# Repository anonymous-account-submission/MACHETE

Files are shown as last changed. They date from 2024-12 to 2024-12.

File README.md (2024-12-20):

# Motor Assisted Commutator to Harness Electronics in Tethered Experiments (MACHETE)

MACHETE is a motor assisted commutator that allows researchers to capture high-fidelity electro-optical data during tethered freely-moving behavior experiments with mice.



# Custom Arduino Printed Circuit Board Shield:
Our motor assisted commutator is driven and controlled by an Arduino Nano 3.x, integrated within a pair of custom printed circuit boards (PCBs) which allow users to interface with both data aquisition computers and existing commercial optogenetic and electrophysiological devices. 



# Commercially Available and Custom Made Parts 

<table class="table table-bordered table-hover table-condensed">
<thead>
<tr>
<th title="Field #1">Part Number</th>
<th title="Field #2">Distributor</th>
<th title="Field #3">Part Name</th>
<th title="Field #4">Distributor Part Number</th>
<th title="Field #5">Quantity Needed</th>
</tr>
</thead>
<tbody>
<tr>
<td align="right">1</td>
<td>Digikey</td>
<td>Micro USB 2.0 Connector</td>
<td>609-4613-1-ND</td>
<td>1</td>
</tr>
<tr>
<td align="right">2</td>
<td>Digikey</td>
<td>Connector Receptacle</td>
<td>WM3917CT-ND</td>
<td>1</td>
</tr>
<tr>
<td align="right">3</td>
<td>Digikey</td>
<td>Resistor 390 Ohm</td>
<td>311-390CRCT-ND</td>
<td>1</td>
</tr>
<tr>
<td align="right">4</td>
<td>Digikey</td>
<td>Toggle Switch</td>
<td>CKN1783CT-ND</td>
<td>1</td>
</tr>
<tr>
<td align="right">5</td>
<td>Digikey</td>
<td>Arduino Nano 3.x</td>
<td>1050-1001-ND</td>
<td>1</td>
</tr>
<tr>
<td align="right">6</td>
<td>Digikey</td>
<td>Mini USB 2.0 Connector</td>
<td>UE25BE5510H-ND</td>
<td>1</td>
</tr>
<tr>
<td align="right">7</td>
<td>Digikey</td>
<td>Right Angle Connector</td>
<td>WM1743-ND</td>
<td>1</td>
</tr>
<tr>
<td align="right">8</td>
<td>Digikey</td>
<td>Resistor 100k Ohm 0805</td>
<td>311-100KCRCT-ND</td>
<td>6</td>
</tr>
<tr>
<td align="right">9</td>
<td>Digikey</td>
<td>Hall Effect Sensor</td>
<td>AS5600-ASOMCT-ND</td>
<td>1</td>
</tr>
<tr>
<td align="right">10</td>
<td>Digikey</td>
<td>Capacitor 1 µF 0805</td>
<td>1276-1066-1-ND</td>
<td>1</td>
</tr>
<tr>
<td align="right">11</td>
<td>Digikey</td>
<td>Capacitor 10 µF 0805</td>
<td>445-7644-1-ND</td>
<td>1</td>
</tr>
<tr>
<td align="right">12</td>
<td>Digikey</td>
<td>Connector Receptacle</td>
<td>WM4783CT-ND</td>
<td>1</td>
</tr>
<tr>
<td align="right">13</td>
<td>Digikey</td>
<td>Resistor 10k Ohm 0805</td>
<td>RMCF0805FT10K0CT-ND</td>
<td>2</td>
</tr>
<tr>
<td align="right">14</td>
<td>Digikey</td>
<td>Motor Driver 20-QFN (3x3)</td>
<td>175-TMC6300-LA-TCT-ND</td>
<td>1</td>
</tr>
<tr>
<td align="right">15</td>
<td>Digikey</td>
<td>Resistor 120 mOhms 0805</td>
<td>RL12S.12FCT-ND</td>
<td>1</td>
</tr>
<tr>
<td align="right">16</td>
<td>Digikey</td>
<td>Capacitor 0.1 µF 0805</td>
<td>478-KGM21NR71H104KTCT-ND</td>
<td>3</td>
</tr>
<tr>
<td align="right">17</td>
<td>Digikey</td>
<td>Brushless DC Motor</td>
<td>1568-ROB-20441-ND</td>
<td>1</td>
</tr>
<tr>
<td align="right">18</td>
<td>Mouser</td>
<td>Red LED</td>
<td>696-SMLFT0805SRCTR</td>
<td>1</td>
</tr>
<tr>
<td align="right">19</td>
<td>Adafruit</td>
<td>M3 x 4mm threaded insert</td>
<td>4255</td>
<td>1 (Pack of 50)</td>
</tr>
<tr>
<td align="right">20</td>
<td>McMaster-Carr</td>
<td>M2 x 4mm threaded insert</td>
<td>94180A312</td>
<td>1 (Pack of 100)</td>
</tr>
<tr>
<td align="right">21</td>
<td>McMaster-Carr</td>
<td>Ball Bearing 6 mm shaft</td>
<td>4668K122</td>
<td>1</td>
</tr>
<tr>
<td align="right">22</td>
<td>McMaster-Carr</td>
<td>M3-0.5 x 6mm screw</td>
<td>91290A111</td>
<td>1</td>
</tr>
<tr>
<td align="right">23</td>
<td>McMaster-Carr</td>
<td>M3-0.5 x 10mm screw</td>
<td>91290A115</td>
<td>1</td>
</tr>
<tr>
<td align="right">24</td>
<td>McMaster-Carr</td>
<td>M2-0.4 x 8mm screw</td>
<td>91290A015</td>
<td>1</td>
</tr>
<tr>
<td align="right">25</td>
<td>Taidacent</td>
<td>Rotary Electrical Slip Ring</td>
<td>734831002031</td>
<td>1</td>
</tr>
<tr>
<td align="right">26</td>
<td>K&J Magnetics, Inc</td>
<td>Magnet (5 mm x 1mm)</td>
<td>D301</td>
<td>1</td>
</tr>
<tr>
<td align="right">27</td>
<td>Maxx Model</td>
<td>M1.6 x 4mm screw</td>
<td>M1640HCS</td>
<td>2</td>
</tr>
<tr>
<td align="right">28</td>
<td>Custom Parts</td>
<td>Top Case</td>
<td>3-D Printing</td>
<td>1</td>
</tr>
<tr>
<td align="right">29</td>
<td>Custom Parts</td>
<td>PCB attachment</td>
<td>3-D Printing</td>
<td>1</td>
</tr>
<tr>
<td align="right">30</td>
<td>Custom Parts</td>
<td>Static PCB</td>
<td>PCB Manufacturing (JLC PCB)</td>
<td>1</td>
</tr>
<tr>
<td align="right">31</td>
<td>Custom Parts</td>
<td>Dynamic PCB</td>
<td>PCB Manufacturing (JLC PCB)</td>
<td>1</td>
</tr>
<tr>
<td align="right">32</td>
<td>Custom Parts</td>
<td>Small Gear</td>
<td>3-D Printing</td>
<td>1</td>
</tr>
<tr>
<td align="right">33</td>
<td>Custom Parts</td>
<td>Shield</td>
<td>3-D Printing</td>
<td>1</td>
</tr>
<tr>
<td align="right">34</td>
<td>Custom Parts</td>
<td>Cable Holder</td>
<td>3-D Printing</td>
<td>1</td>
</tr>
<tr>
<td align="right">35</td>
<td>Custom Parts</td>
<td>Outer Gear</td>
<td>3-D Printing</td>
<td>1</td>
</tr>
</tbody>
</table>

This [document](https://github.com/anonymous-account-submission/MACHETE/blob/bac1c05d11be4005d82bf26546d7f61cbe5a9f60/3-MACHETE-Custom-Parts-Table.pdf) outlines the design of each of the custom pieces and the file types found within this repository that can be used to replicate the system. The following [spreadsheet](https://github.com/anonymous-account-submission/MACHETE/blob/89ad60d1f6e04f39b38d436aee46013fde03fa46/2-MACHETE-Bill-of-Materials-and-Assembly-Spreadsheet.xlsx) outlines the total cost of the motor assisted commutator.  

**Here is a list of the manufacturers we purchased materials from:** 
- Digikey
- Mouser
- Adafruit 
- McMaster-Carr
- Taidacent
- K&J Magnetics, Inc
- Maxx Model

# Step-by-Step Building Guide



This following [guide](https://github.com/anonymous-account-submission/MACHETE/blob/89ad60d1f6e04f39b38d436aee46013fde03fa46/4-MACHETE-Step-by-Step-Guide.pdf) provides a step-by-step walkthrough for building and testing each component of our motor assisted commutator. This document includes diagrams and explanations for assembling each component. 

# Software Installation Guide and Dependencies

Following this installation guide will ensure that your MACHETE system will be able to run the required Arduino IDE sketches to function. 

**Required Software and Applications**:
- [Arduino IDE](https://www.arduino.cc/en/software)
- [BORIS](https://github.com/olivierfriard/BORIS)
  
# Contact

Further information and requests for resources should be directed to and will be fulfilled by the lead author, [Lead Author Name and Email]. Example commutator data is available upon request to the corresponding author, [Corresponding Author Name and Email].

# Citation 

If you replicate this system in your own labs or use parts of our designs and code, we kindly ask that you please cite this [page](https://github.com/anonymous-account-submission/MACHETE) [1].

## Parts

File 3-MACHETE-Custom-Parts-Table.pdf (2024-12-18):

Custom Part and Filetype: | 3-D Rendering

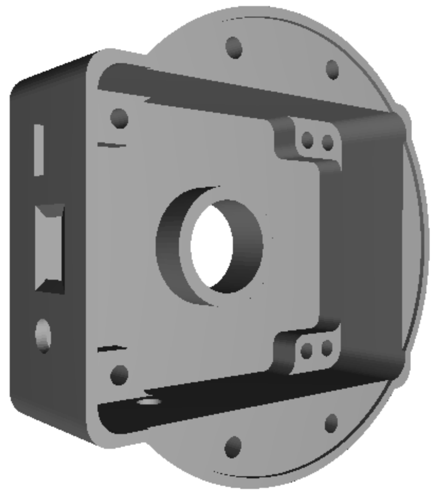
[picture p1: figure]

Top Case Part1_Top_Case.stl

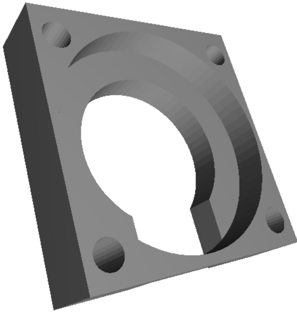
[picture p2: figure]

PCB Attachment Part3_PCB_Attachment.stl

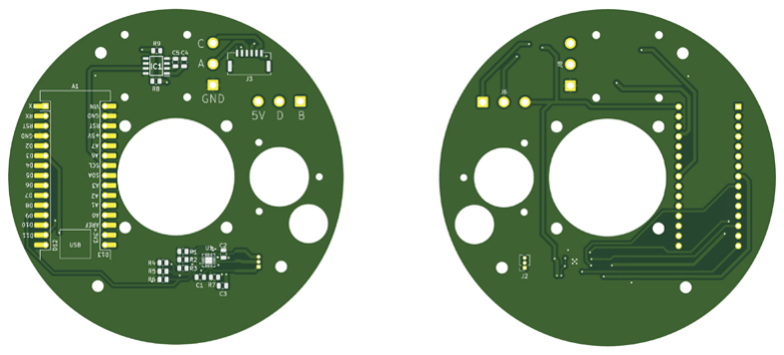
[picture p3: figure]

Static PCB Static_PCB_Fab_Files Folder

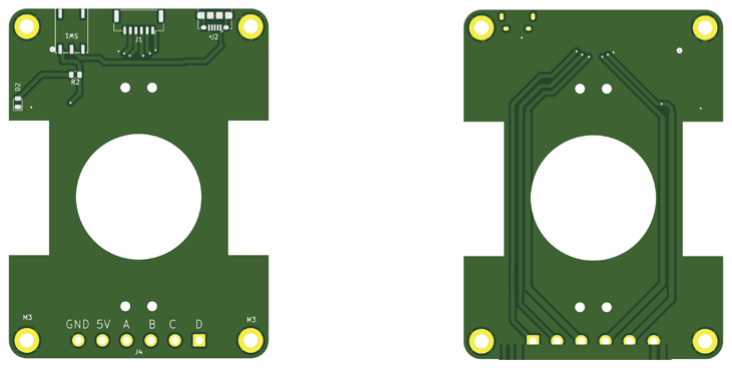
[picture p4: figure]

Dynamic PCB Dynamic_PCB_Fab_Files Folder

Custom Part and Filetype: | 3-D Rendering

Small Gear Part11_Small_Gear.stl

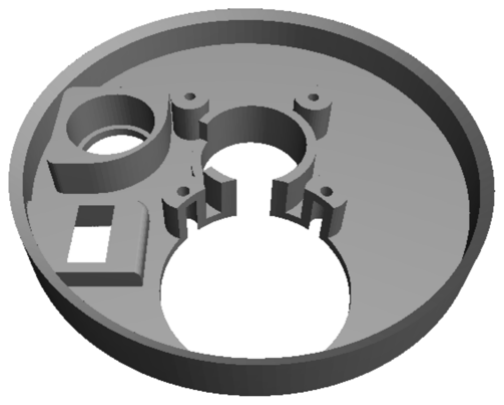
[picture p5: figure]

Shield Part13_Shield.stl

Cable Holder Part14_Cable_Holder.stl

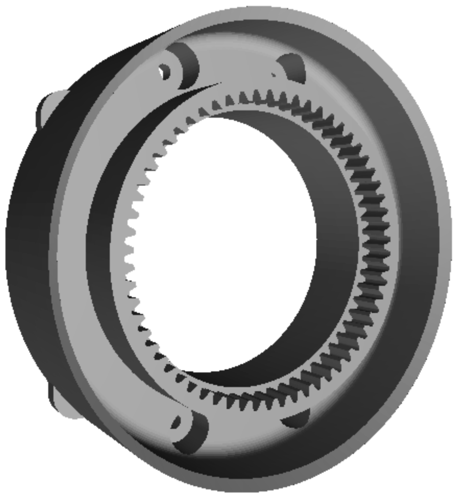
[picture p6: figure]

Outer Gear Part17_Outer_Gear.stl

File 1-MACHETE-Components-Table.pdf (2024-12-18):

Part Name | Part / Identification Number | Quantity

Digikey

Micro USB 2.0 Connector | 609-4613-1-ND | 1
Connector Receptacle | WM3917CT-ND | 1
Resistor 390 Ohm | 311-390CRCT-ND | 1
Toggle Switch | CKN1783CT-ND | 1
Arduino Nano 3.x | 1050-1001-ND | 1
Mini USB 2.0 Connector | UE25BE5510H-ND | 1
Right Angle Connector | WM1743-ND | 1
Resistor 100k Ohm 0805 | 311-100KCRCT-ND | 6
Hall Effect Sensor | AS5600-ASOMCT-ND | 1
Capacitor 1 µF 0805 | 1276-1066-1-ND | 1
Capacitor 10 µF 0805 | 445-7644-1-ND | 1
Connector Receptacle | WM4783CT-ND | 1
Resistor 10k Ohm 0805 | RMCF0805FT10K0CT-ND | 2
Motor Driver 20-QFN (3x3) | 175-TMC6300-LA-TCT-ND | 1
Resistor 120 mOhms 0805 | RL12S.12FCT-ND | 1
Capacitor 0.1 µF 0805 | 478-KGM21NR71H104KTCT-ND | 3
Brushless DC Motor | 1568-ROB-20441-ND | 1

Mouser

Red LED | ID: 696-SMLFT0805SRCTR | 1

Adafruit

M3 x 4mm threaded insert | 4255 | 1 (Pack of 50)

McMaster-Carr

M2 x 4mm threaded insert | 94180A312 | 1 (Pack of 100)
Ball Bearing 6 mm shaft | 4668K122 | 1

M3-0.5 x 6mm screw | 91290A111 | 1
M3-0.5 x 10mm screw | 91290A115 | 1
M2-0.4 x 8mm screw | 91290A015 | 1

Taidacent

Rotary Electrical Slip Ring (M2 x 10mm screws included) | 734831002031 | 1

K&J Magnetics, Inc

Magnet (5 mm x 1mm) | D301 | 1

Maxx Model

M1.6 x 4mm screw | M1640HCS | 1

Custom Parts

Top Case | 3-D Printing | 1
PCB attachment | 3-D Printing | 1
Static PCB | PCB Manufacturing (JLC PCB) | 1
Dynamic PCB | PCB Manufacturing (JLC PCB) | 1
Small Gear | 3-D Printing | 1
Shield | 3-D Printing | 1
Cable Holder | 3-D Printing | 1
Outer Gear | 3-D Printing | 1

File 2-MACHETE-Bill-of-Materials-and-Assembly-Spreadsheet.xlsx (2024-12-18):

STATIC PCB BILL OF MATERIALS |  | QTY | Link
J2 | USB_Micro-B_Amphenol_10118194_Horizontal | 1 | https://www.digikey.com/en/products/detail/amphenol-icc-(fci)/10118192-0001LF/2785378
D2 | 0805 RED LED | 1 | https://www.mouser.com/ProductDetail/Lumex/SML-LXFT0805SRC-TR
J1 | Molex_CLIK-Mate_502386-0670_1x06-1MP_P1.25mm_Horizontal | 1 | https://www.digikey.com/en/products/detail/molex/5023860670/2421477
R2 | 0805 Resistor 390 Ohms | 1 | https://www.digikey.com/en/products/detail/yageo/RC0805FR-07390RL/727902
SW1 | GT11MSABE_CNK Surface mounted Switch | 1 | https://www.digikey.com/en/products/detail/c-k/GT11MSABE/683345
Dynamic PCB BILL OF MATERIALS |  | QTY | Link
A1 | Arduino_Nano_v3.x | 1 | https://www.digikey.com/en/products/detail/arduino/A000005/2638989
J7 | AMPHENOL_UE25BE5510H | 1 | https://www.digikey.com/en/products/detail/amphenol-cs-commercial-products/UE25BE5510H/7805253
J2 | 0530480310 MOLEX | 1 | https://www.digikey.com/en/products/detail/molex/0530480310/242865
R1,R6,R2,R3,R4,R5 | 100kOhms 0805 Resistor | 6 | https://www.digikey.com/en/products/detail/yageo/RC0805FR-07100KL/727544
IC1 | AS5600-ASOM - SOIC127P600X175-8N | 1 | https://www.digikey.com/en/products/detail/ams-osram-usa-inc/AS5600-ASOM/4914332
C5 | 1uF 0805 Capacitor | 1 | https://www.digikey.com/en/products/detail/samsung-electro-mechanics/CL21B105KAFNNNE/3886724
C3 | 10uF 0805 Capacitor | 1 | https://www.digikey.com/en/products/detail/tdk-corporation/C2012X5R1C106K085AC/2733079
J3 | Molex_CLIK-Mate_502382-0670_1x06-1MP_P1.25mm_Vertical | 1 | https://www.digikey.com/en/products/detail/molex/5023820670/2649170
R9,R8 | 10kOhms 0805 Resistor | 2 | https://www.digikey.com/en/products/detail/stackpole-electronics-inc/RMCF0805FT10K0/1760676
U1 | TMC6300-LA-T 21-100586_K2033&plus_1C_ADI | 1 | https://www.digikey.com/en/products/detail/analog-devices-inc/tmc6300-la-t/12090904
R7 | 120 milliOhms 0805 Resistor | 1 | https://www.digikey.com/en/products/detail/susumu/RL1220S-R12-F/432481
C2,C4,C1 | 100nF 0805 Capacitor | 3 | https://www.digikey.com/en/products/detail/kyocera-avx/KGM21NR71H104KT/563505
ASSEMBLY LIST
PART NUMBER | Description | Quantity | Figure 2 | Link / Note | STL FILE
1 | Top Case | 1 | a | 3D Printed | Part1_Top_Case.stl
2 | M3, 4mm threaded Insert | 12 | a | https://www.amazon.com/M3x4-0mm-OD4-6mm-Staking-Threaded-Quik-Tek/dp/B08T7M2H4S
3 | PCB attachement | 1 | b | 3D Printed | Part3_PCB_Attachment.stl
4 | M2, 4mm threaded isert | 4 | b | https://www.amazon.com/gp/aw/d/B088QJG676/
5 | Rotary encoder | 1 | c | https://www.amazon.com/Taidacent-Conductive-Electrical-Rotating-Connector/dp/B07YJNWJ4M?th=1
6 | Static PCB | 1 | c | See : Static PCB Bill of materials
7 | M2, 10 mm screw | 4 | c | Typically included with part #5
8 | Dynamic PCB | 1 | d | See : Dynamic PCB Bill of materials
9 | Motor | 1 | d | https://www.digikey.com/en/products/detail/sparkfun-electronics/ROB-20441/16820876
10 | M1.6, 4mm screw | 3 | d | https://www.amazon.com/M1-6x4mm-0-35mm-Pitch-Socket-100pcs/dp/B00XP4ZWY2
11 | Small Gear | 1 | d | 3D Printed | Part11_Small_Gear.stl
12 | Ball Bearing 6*17*6mm | 1 | e | https://www.mcmaster.com/4668k122/
13 | Shield | 1 | e | 3D Printed | Part13_Shield.stl
14 | Cable Holder | 1 | f | 3D Printed | Part14_Cable_Holder.stl
15 | 5*1mm magnet (diam. Magnetized) | 1 | f | https://www.kjmagnetics.com/proddetail.asp?prod=D301
16 | M3 x 0.5 mm Thread, 6 mm Long | 4 | g | https://www.mcmaster.com/91290A111/
17 | Outer gear | 1 | h | 3D Printed | Part17_Outer_Gear.stl
18 | M3 x 0.5 mm Thread, 10 mm Long | 4 | h | https://www.mcmaster.com/91290A115/
19 | M2 - 8mm | 4 | i | https://www.mcmaster.com/91290A015/

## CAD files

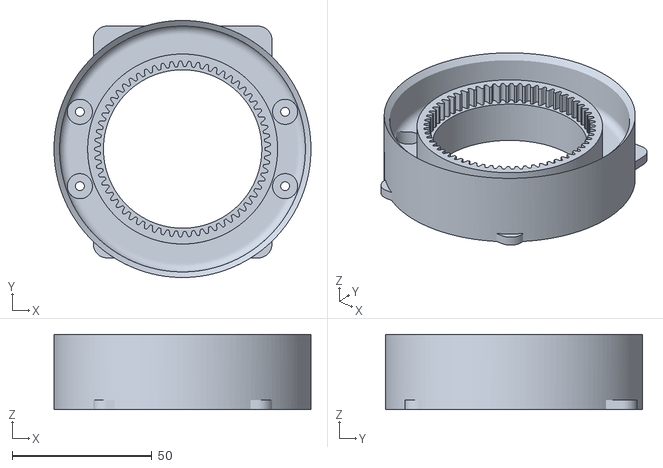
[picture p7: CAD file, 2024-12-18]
Building Files/Part17_Outer_Gear.stl
92.0 x 92.0 x 26.9

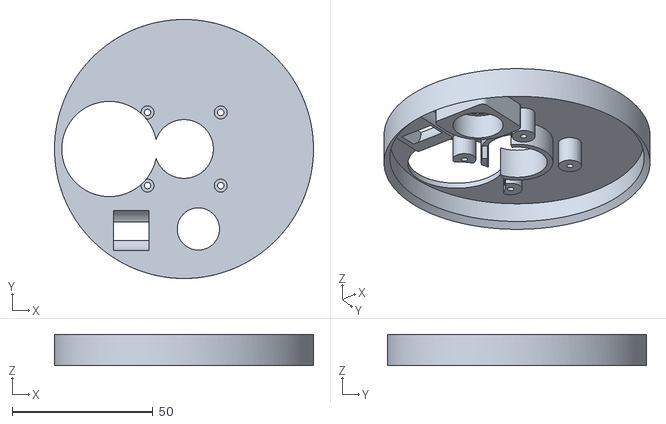
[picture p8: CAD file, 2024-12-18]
Building Files/Part13_Shield.stl
92.0 x 92.0 x 11.1

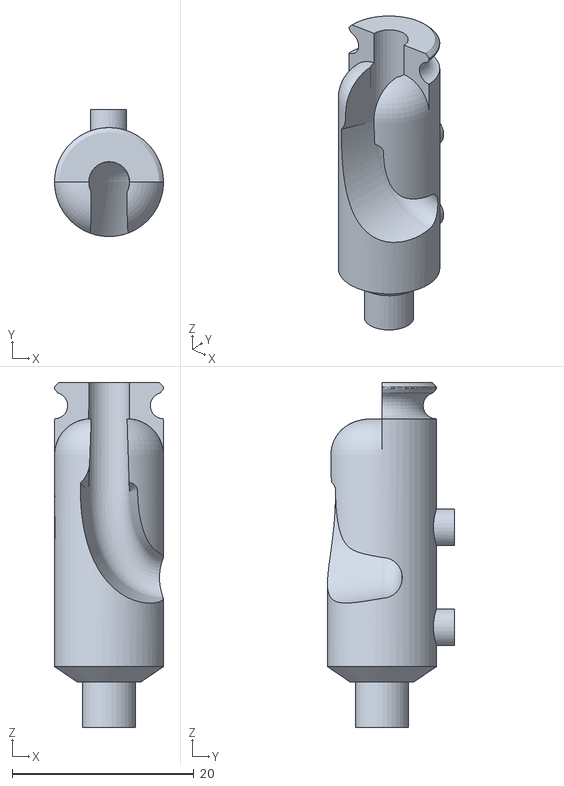
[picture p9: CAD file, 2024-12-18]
Building Files/Part14_Cable_Holder.stl
12.0 x 14.0 x 38.0

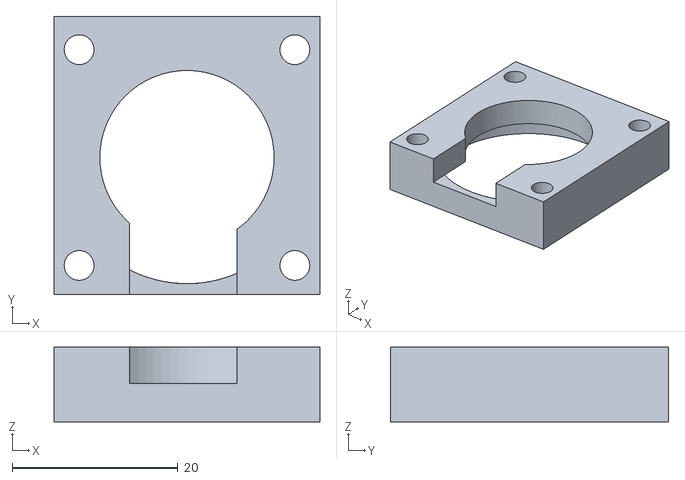
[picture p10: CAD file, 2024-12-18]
Building Files/Part3_PCB_Attachment.stl
32.0 x 33.5 x 9.00

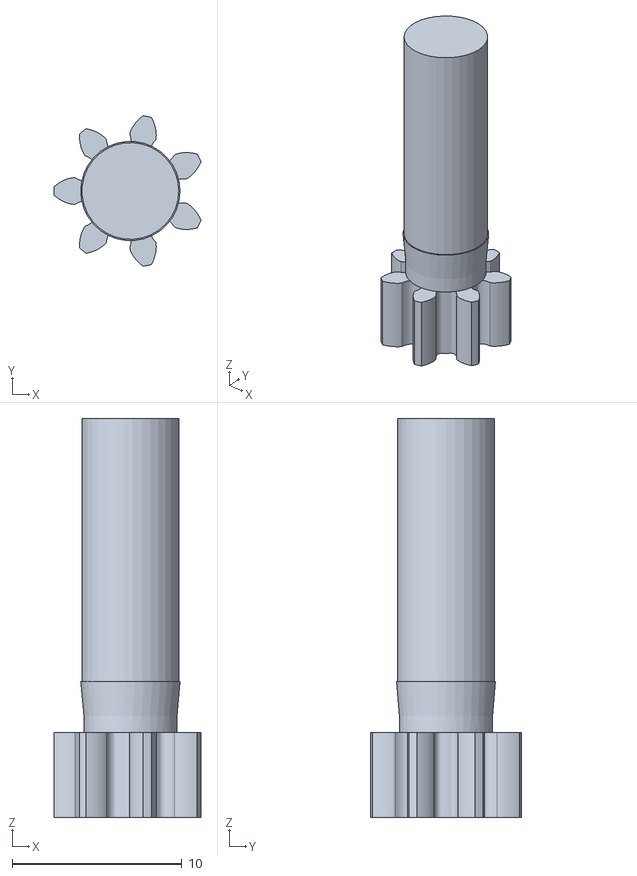
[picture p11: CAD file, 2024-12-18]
Building Files/Part11_Small_Gear.stl
8.66 x 8.87 x 23.5
